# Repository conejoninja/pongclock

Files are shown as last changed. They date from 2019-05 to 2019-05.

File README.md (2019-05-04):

PONG clock
==========
Show the time while playing a game of PONG.

PONG clock

[Youtube video](https://www.youtube.com/watch?v=r6KoyicwPws).

This clock should not be used for time-sensitive tasks as it might run a couple of seconds late to adjust the time change to the game.

## Bill of Materials
* [BBC micro:bit](https://www.amazon.es/BBC-Placa-circuitos-Micro-bit/dp/B01G8WUGWU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) (you could use a adafruit itsybitsy m0 or any other microcontroller compatible with tinygo)
* [sensor:bit](https://www.aliexpress.com/item/Sensor-bit-Breakout-Expansion-Board-IO-Port-Extension-for-BBC-Micro-bit-Microbit-Kids-Programming-Learning/32916721349.html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) expansion board for BBC micro:bit
* [RTC DS3231](https://www.aliexpress.com/item/DS3231-AT24C32-IIC-High-Precision-RTC-Module-Clock-Timer-Memory-Module/2037934408.html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,searchweb201602_4_10065_10068_10547_319_10891_317_10548_10696_10084_453_454_10083_10618_10307_10820_10821_10301_10303_537_536_10059_10884_10887_321_322_10103,searchweb201603_52,ppcSwitch_0&algo_expid=d68ff566-69ce-4556-8398-802872637432-0&algo_pvid=d68ff566-69ce-4556-8398-802872637432)
* [HUB75 64x32 RGB LED matrix](https://www.aliexpress.com/item/64x32-indoor-RGB-hd-p4-indoor-led-module-video-wall-high-quality-P2-5-P3-P4/32754106669.html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)
* dupont female headers, wires and solder

## Circuit and connections

Connect the RTC DS3231 to the I²C interface (bottom right corner of the sensor:bit expansion board). The rest of the pins as described in the [microbit_connections.md](https://github.com/conejoninja/pongclock/blob/master/microbit_connections.md) file or the following image, be aware there are some connections between the two connectors of the RGB matrix and between the left one and the microbit expansion board:

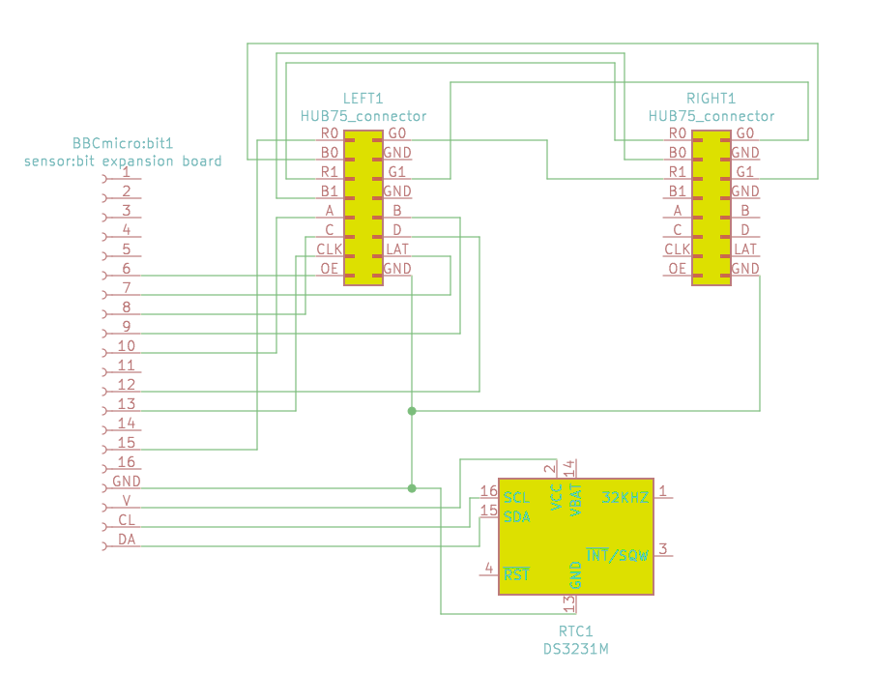
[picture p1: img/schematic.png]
Schematic


## 3D printed cover

I made a simple [3D printed cover](https://github.com/conejoninja/pongclock/blob/master/3Dfiles/back.cover.stl). There are 3 tabs pre-cut to pass the power cable if needed, two at the sides and one at the bottom. There's also three holes for screw hooks on top.

## License

The MIT License (MIT)

Copyright 2019 Daniel Esteban - conejo@conejo.me

Permission is hereby granted, free of charge, to any person obtaining a copy of this software and associated documentation files (the "Software"), to deal in the Software without restriction, including without limitation the rights to use, copy, modify, merge, publish, distribute, sublicense, and/or sell copies of the Software, and to permit persons to whom the Software is furnished to do so, subject to the following conditions:

The above copyright notice and this permission notice shall be included in all copies or substantial portions of the Software.

THE SOFTWARE IS PROVIDED "AS IS", WITHOUT WARRANTY OF ANY KIND, EXPRESS OR IMPLIED, INCLUDING BUT NOT LIMITED TO THE WARRANTIES OF MERCHANTABILITY, FITNESS FOR A PARTICULAR PURPOSE AND NONINFRINGEMENT. IN NO EVENT SHALL THE AUTHORS OR COPYRIGHT HOLDERS BE LIABLE FOR ANY CLAIM, DAMAGES OR OTHER LIABILITY, WHETHER IN AN ACTION OF CONTRACT, TORT OR OTHERWISE, ARISING FROM, OUT OF OR IN CONNECTION WITH THE SOFTWARE OR THE USE OR OTHER DEALINGS IN THE SOFTWARE.

## Note

PONG is a trademark of ATARI INTERACTIVE, INC.

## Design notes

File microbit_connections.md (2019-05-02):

micro:bit connections
=====================
You will find some differences among the multiples versions of _hub75_ matrices, but the connector is the same. Some matrices use R1, R2, G1, G2, B1, B2 instead of R0, R1, G0, G1, B0, B1.

| micro:bit | hub75 matrix |
|:-:|:-:|
| P6 | OE |
| P7 | STB/LAT |
| P8 | C |
| P9 | B |
| P10 | A |
| P12 | D |
| P13 /SCK | CLK |
| P15 / MOSI| R0 |
| GND | GND |

Additionally you need to connect some pins from the left, to the right one.

| left connector | right connector |
|:-:|:-:|
| R1 | R0 |
| G1 | G0 |
| B1 | B0 |
| G0 | R1 |
| B0 | G1 |

The pins on the connector are (it could rotated):

|  |  |
|:-:|:-:|
| R0 | G0 |
| B0 | GND |
| R1 | G1 |
| B1 | GND |
| A | B |
| C | D |
| CLK | LAT |
| OE | GND |

DS3231 connections

| DS3231 | micro:bit (sensor:bit) |
|:-:|:-:|
| GND | G |
| VCC | V |
| SDA | DA |
| SCL | CL |

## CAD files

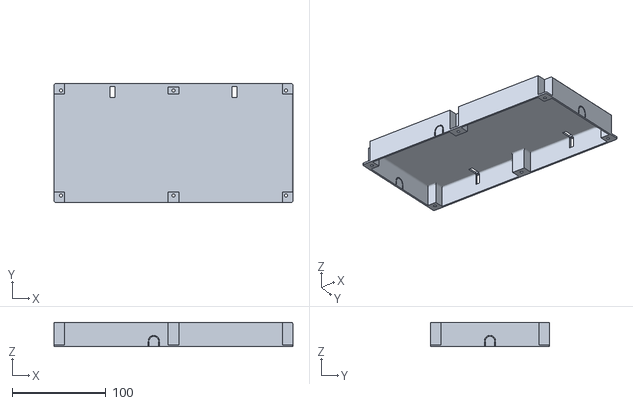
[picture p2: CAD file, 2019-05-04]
3Dfiles/back.cover.stl
255.0 x 127.0 x 26.0

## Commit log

2019-05-01 added BOM
2019-05-04 added 3d printed back cover
    [back.cover.stl]
